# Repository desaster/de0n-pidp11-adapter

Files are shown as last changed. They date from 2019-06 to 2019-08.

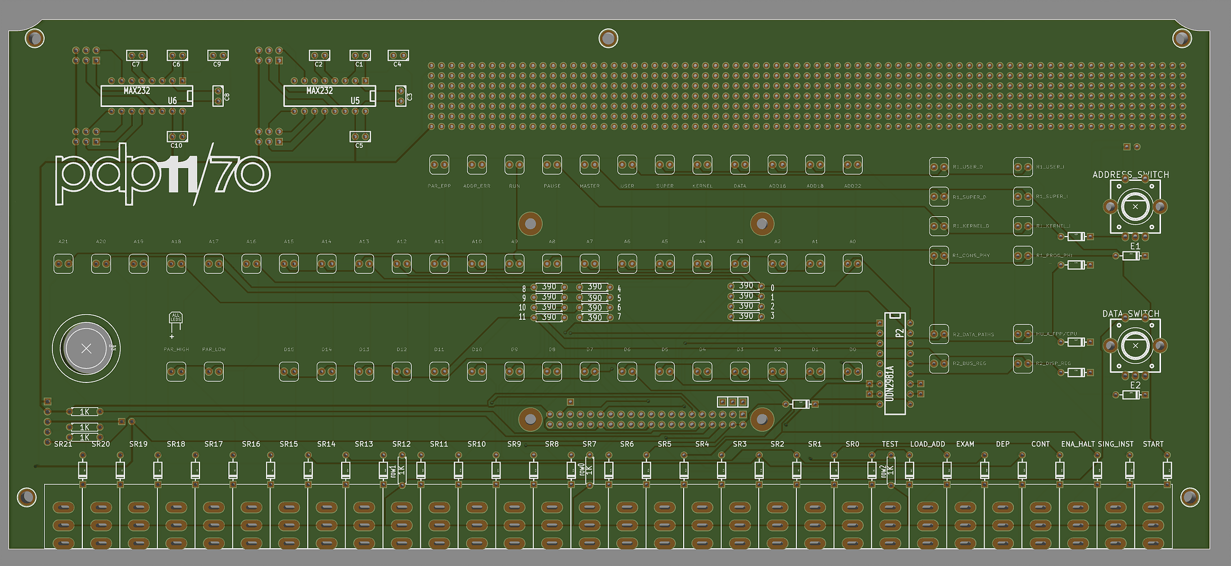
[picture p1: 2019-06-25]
ref/pidp11_front.png

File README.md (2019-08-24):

# DE0-Nano adapter board for PiDP-11

This is an adapter board to connect the
[DE0-Nano  FPGA Development board](http://www.terasic.com.tw/cgi-bin/page/archive.pl?Language=English&No=593)
to the [PiDP-11, PDP-11/70 front panel replica](https://obsolescence.wixsite.com/obsolescence/pidp-11).
It is intended to be used with [PDP2011, an FPGA implementation of PDP-11](http://pdp2011.sytse.net/wordpress/).

In addition to routing the necessary pins to the panel, the board also
includes some components for use with the PDP2011:
* Micro-SDCard connector
* USB-UART bridge using the [CP2102](https://www.silabs.com/products/interface/usb-bridges/classic-usb-bridges/device.cp2102)
* Additional pin headers for a secondary UART connection
* Pin headers for connecting to [PMODNIC100](https://store.digilentinc.com/pmod-nic100-network-interface-controller/)

The pinout is a direct implementation of those
[described by Sytse in his blog](http://pdp2011.sytse.net/wordpress/wiring/).

The components used are basically what I had lying around.
If you wish to make this board yourself, consider changing the design to
match the components most optimal for you.

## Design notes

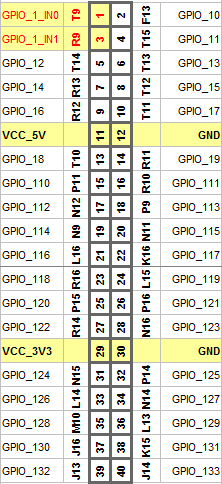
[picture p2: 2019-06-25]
de0n-gpio1.png

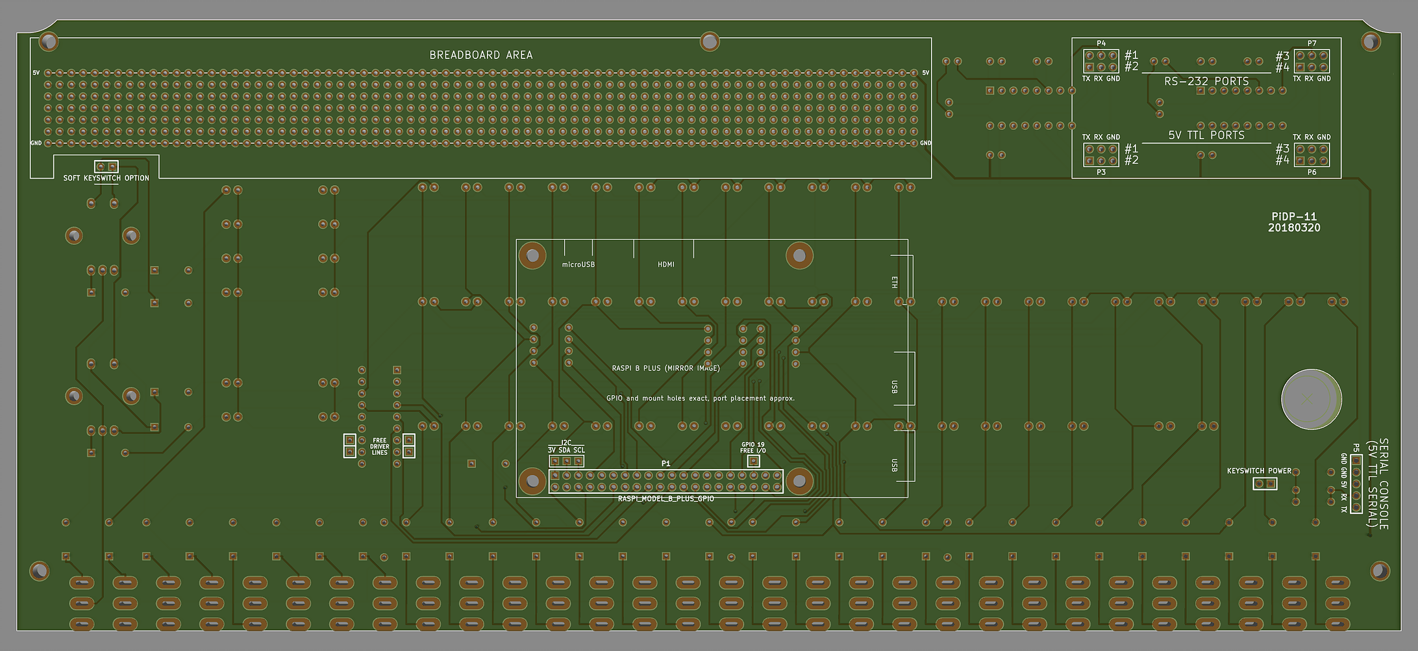
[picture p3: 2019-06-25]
ref/pidp11_back.png

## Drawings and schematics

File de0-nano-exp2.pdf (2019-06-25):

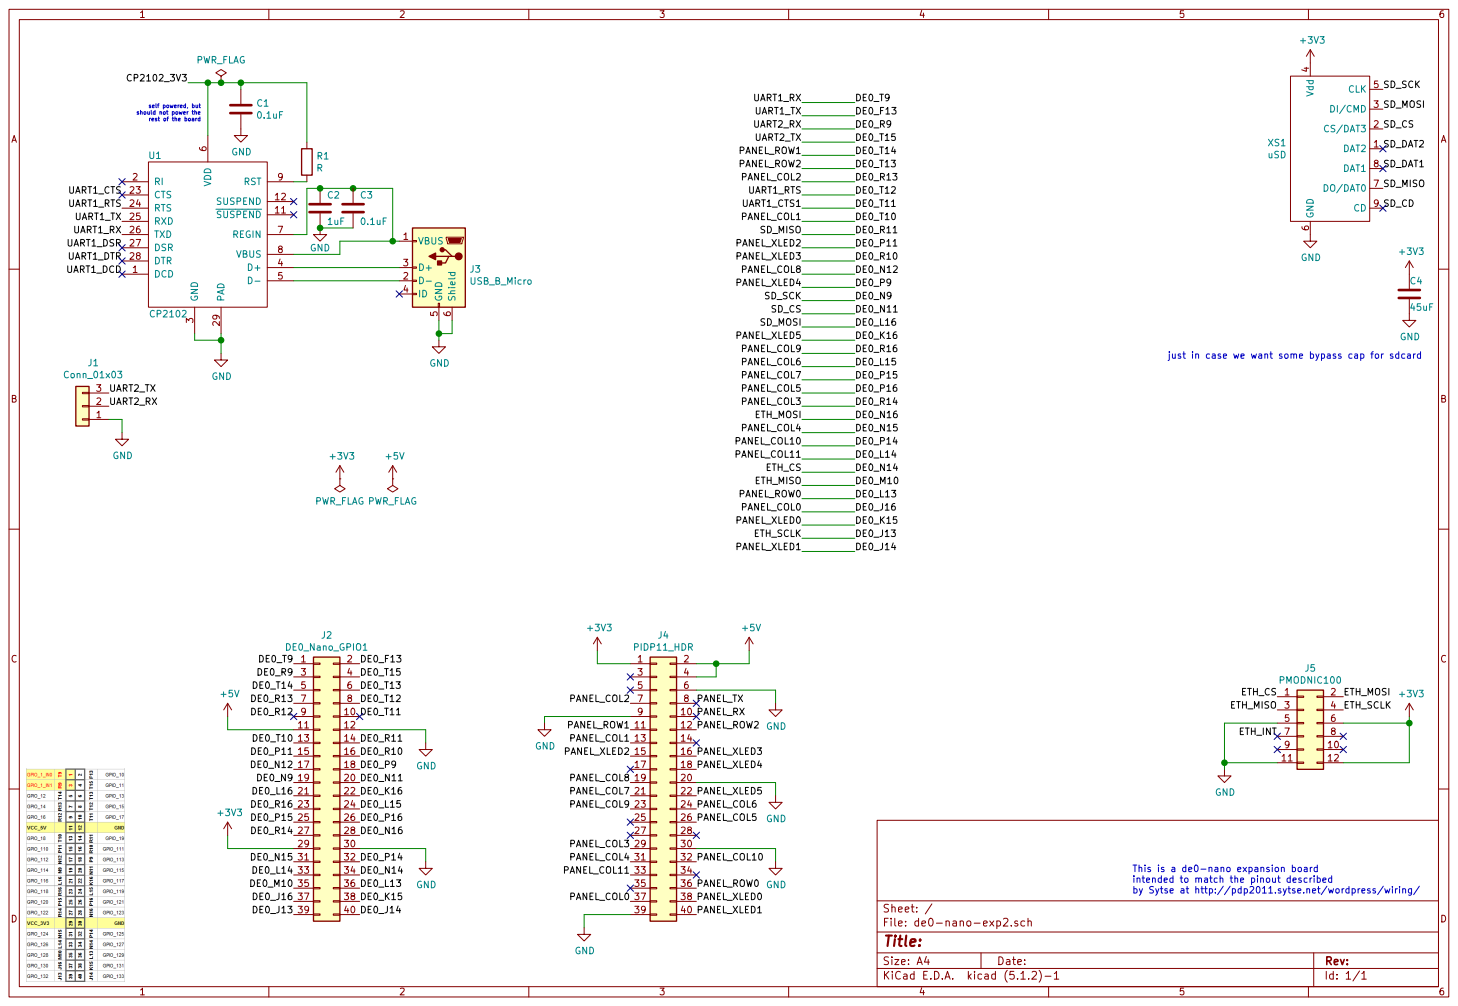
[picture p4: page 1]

self powered, but should not power the

just in case we want some bypass cap for sdcard+3V3 GND

intended to match the pinout described

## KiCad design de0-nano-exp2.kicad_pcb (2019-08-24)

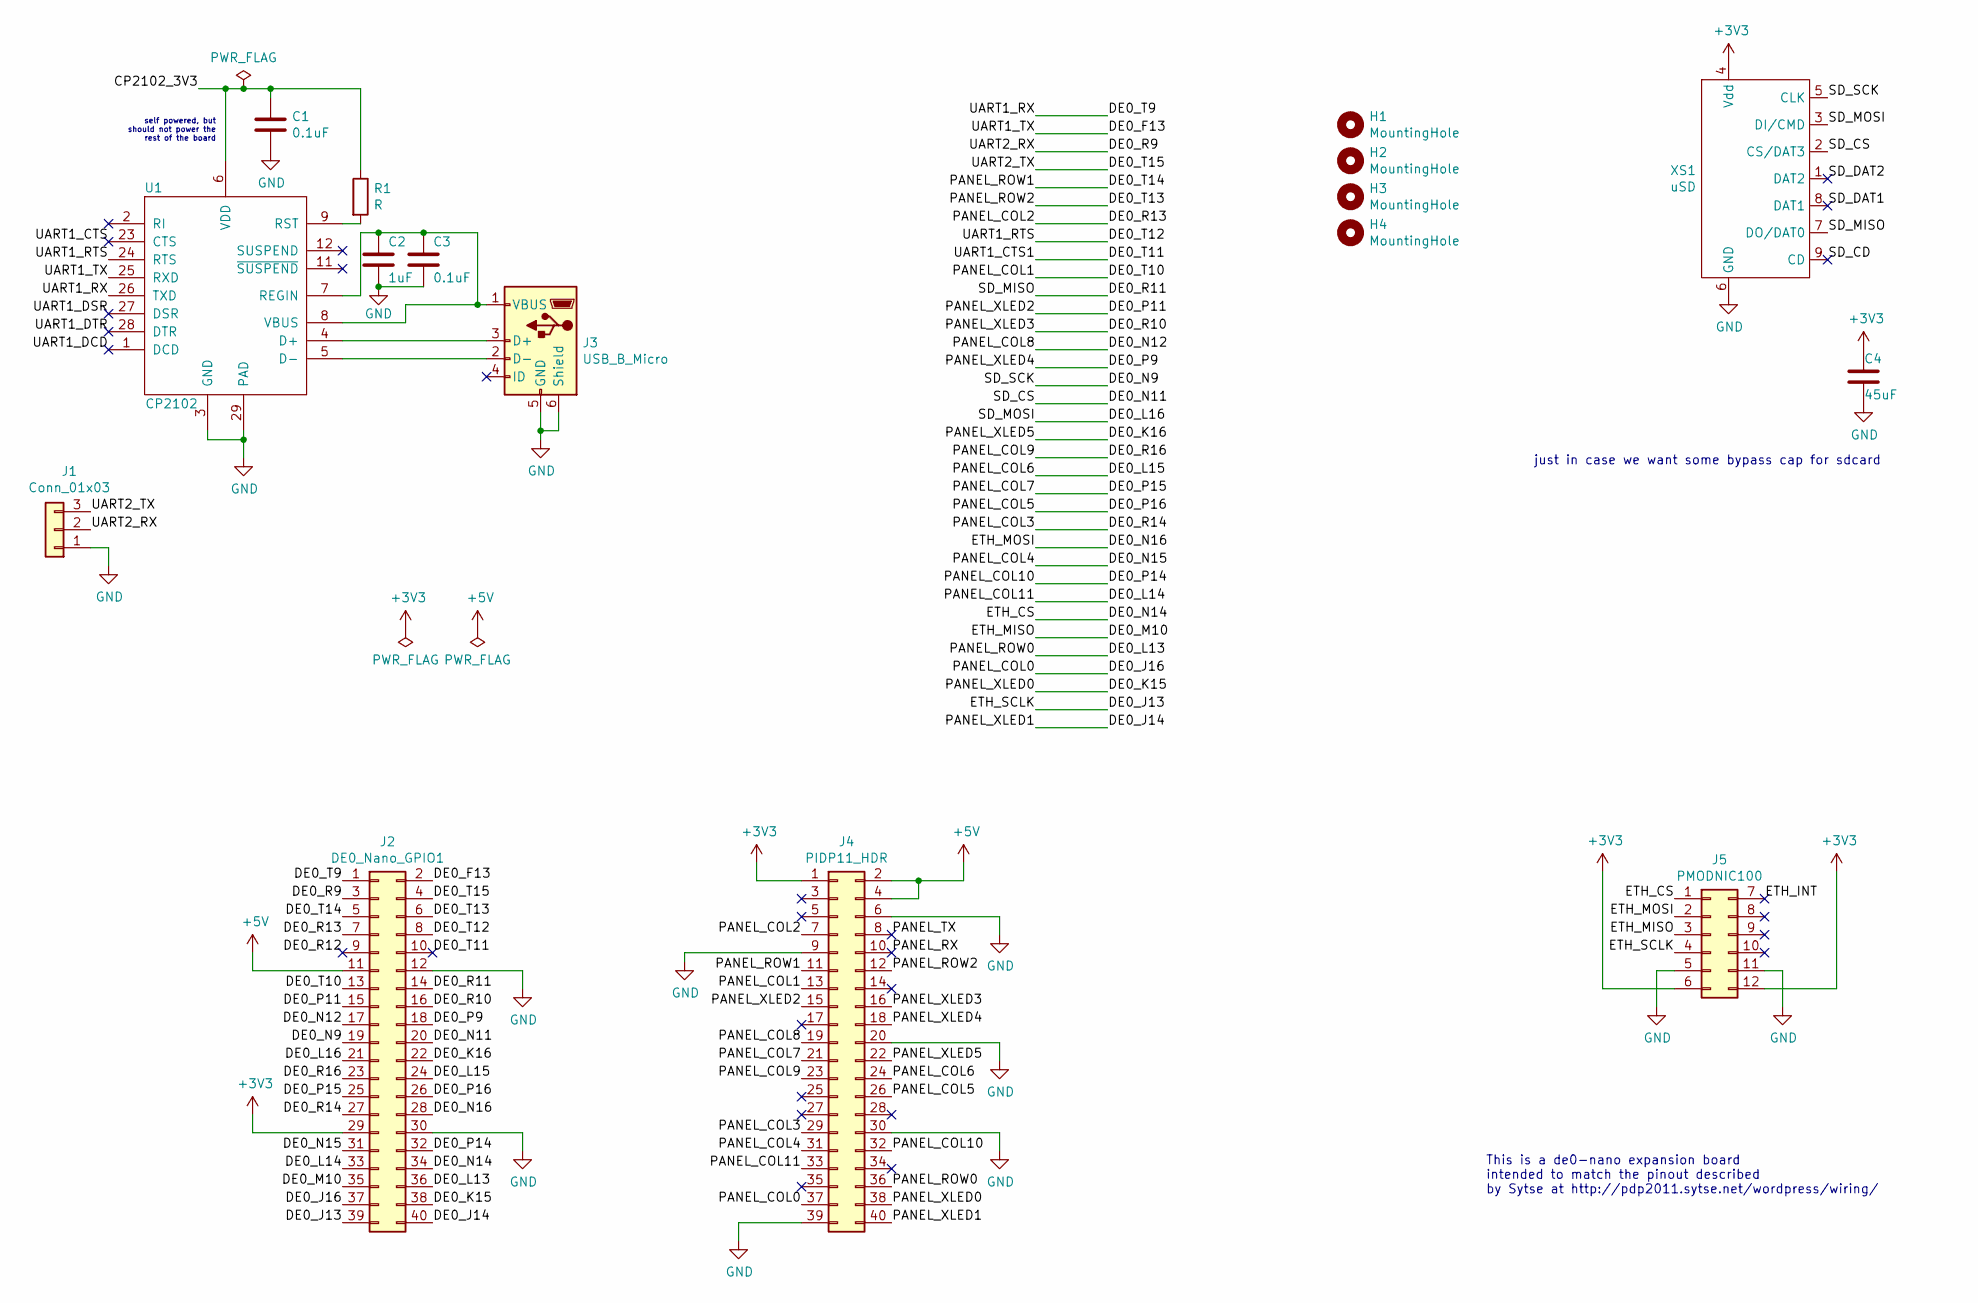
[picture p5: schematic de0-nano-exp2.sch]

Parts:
C1, C3: 0.1uF; C_0805_2012Metric_Pad1.15x1.40mm_HandSolder
C2: 1uF; C_0805_2012Metric_Pad1.15x1.40mm_HandSolder
C4: 45uF; C_0805_2012Metric_Pad1.15x1.40mm_HandSolder
H1, H2, H3, H4: MountingHole; MountingHole_RasPI
J1: Conn_01x03; PinHeader_1x03_P2.54mm_Vertical
J2: DE0_Nano_GPIO1; IDC-Header_2x20_P2.54mm_Vertical
J3: USB_B_Micro; USB_Mini-B_Lumberg_2486_01_Horizontal
J4: PIDP11_HDR; PinHeader_2x20_P2.54mm_Vertical
J5: PMODNIC100; pmodnic
R1: R; R_0805_2012Metric_Pad1.15x1.40mm_HandSolder
U1: CP2102; QFN-28-1EP_5x5mm_Pitch0.5mm
XS1: uSD; Conn_uSDcard

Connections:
+3V3: C4.1, J2.29, J4.1, J5.6, J5.12, XS1.4 (Vdd)
+5V: J2.11, J4.2, J4.4
/CP2102_3V3: C1.1, R1.1, U1.6 (VDD)
/DE0_F13: J2.2, U1.25 (RXD)
/DE0_J13: J2.39, J5.4
/DE0_J14: J2.40, J4.40
/DE0_J16: J2.37, J4.37
/DE0_K15: J2.38, J4.38
/DE0_K16: J2.22, J4.22
/DE0_L13: J2.36, J4.36
/DE0_L14: J2.33, J4.33
/DE0_L15: J2.24, J4.24
/DE0_L16: J2.21, XS1.3 (DI/CMD)
/DE0_M10: J2.35, J5.3
/DE0_N9: J2.19, XS1.5 (CLK)
/DE0_N11: J2.20, XS1.2 (CS/DAT3)
/DE0_N12: J2.17, J4.19
/DE0_N14: J2.34, J5.1
/DE0_N15: J2.31, J4.31
/DE0_N16: J2.28, J5.2
/DE0_P9: J2.18, J4.18
/DE0_P11: J2.15, J4.15
/DE0_P14: J2.32, J4.32
/DE0_P15: J2.25, J4.21
/DE0_P16: J2.26, J4.26
/DE0_R9: J1.2, J2.3
/DE0_R10: J2.16, J4.16
/DE0_R11: J2.14, XS1.7 (DO/DAT0)
/DE0_R12: J2.9
/DE0_R13: J2.7, J4.7
/DE0_R14: J2.27, J4.29
/DE0_R16: J2.23, J4.23
/DE0_T9: J2.1, U1.26 (TXD)
/DE0_T10: J2.13, J4.13
/DE0_T11: J2.10
/DE0_T12: J2.8, U1.24 (RTS)
/DE0_T13: J2.6, J4.12
/DE0_T14: J2.5, J4.11
/DE0_T15: J1.3, J2.4
/ETH_INT: J5.7
/PANEL_RX: J4.10
/PANEL_TX: J4.8
/SD_CD: XS1.9 (CD)
/SD_DAT1: XS1.8 (DAT1)
/SD_DAT2: XS1.1 (DAT2)
/UART1_CTS: U1.23 (CTS)
/UART1_DCD: U1.1 (DCD)
/UART1_DSR: U1.27 (DSR)
/UART1_DTR: U1.28 (DTR)
GND: C1.2, C2.2, C3.2, C4.2, J1.1, J2.12, J2.30, J3.5 (GND), J3.6 (Shield), J4.6, J4.9, J4.20, J4.30, J4.39, J5.5, J5.11, U1.3 (GND), U1.29 (PAD), XS1.6 (GND)
unnamed: C2.1, C3.1, J3.1 (VBUS), U1.7 (REGIN), U1.8 (VBUS)
unnamed: J3.2 (D-), U1.5 (D-)
unnamed: J3.3 (D+), U1.4 (D+)
unnamed: R1.2, U1.9 (RST)

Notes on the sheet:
This is a de0-nano expansion board intended to match the pinout described by Sytse at http://pdp2011.sytse.net/wordpress/wiring/
just in case we want some bypass cap for sdcard
self powered, but should not power the rest of the board

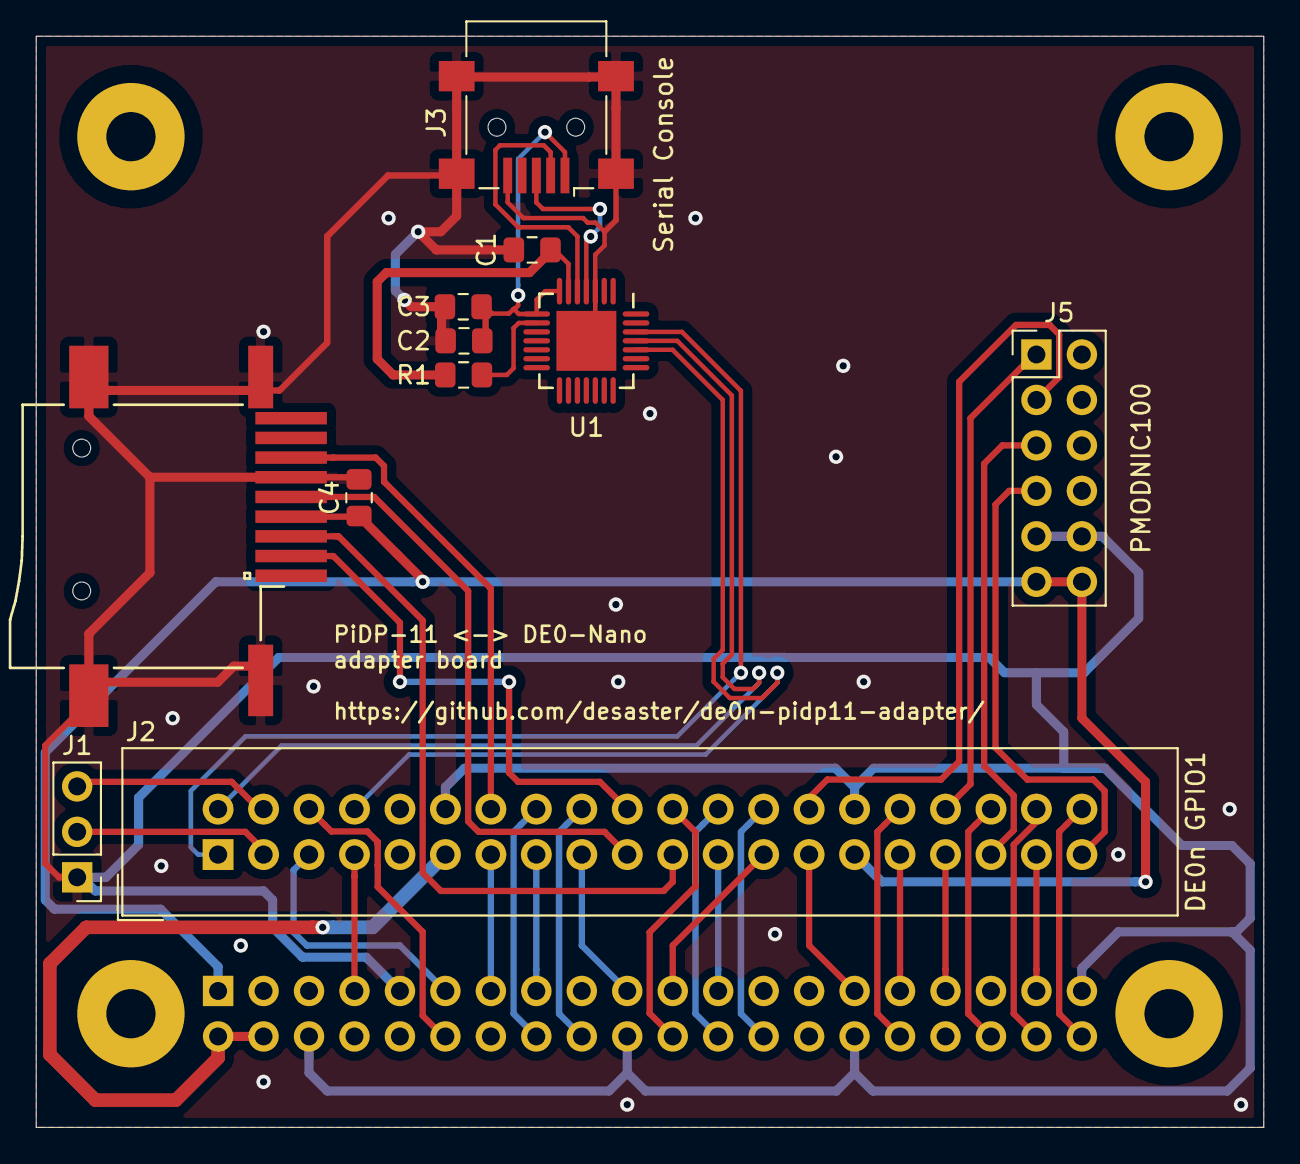
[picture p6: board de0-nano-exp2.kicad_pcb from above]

Board: 2 copper layers, 68.6 x 61.0 mm, 16 parts (1 on the bottom side), 42 nets.
